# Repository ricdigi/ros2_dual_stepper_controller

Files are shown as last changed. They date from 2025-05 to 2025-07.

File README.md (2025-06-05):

## Introduction

This repository presents a complete example of how to repurpose an **ANET A8 3D printer motherboard** into a functional actuator system for a differential drive robot, fully integrated with the **ROS 2 control framework** (`ros2_control`). It provides both the **firmware** that runs on the microcontroller and the **hardware interface plugin** required to bridge the physical system with the ROS 2 ecosystem.

This project serves two main purposes:

1. **Hardware Repurposing Reference**: It provides a practical, working example of how inexpensive 3D printer electronics can be reused in robotics applications.
2. **ROS 2 Control Integration Example**: It offers a minimal but complete implementation of a custom hardware plugin for `ros2_control`, useful as a reference or learning resource.

The actuator system is composed of **two stepper motors**, each equipped with an **AS5600 absolute magnetic encoder** to track shaft position. The motors are driven by **A4988 stepper drivers** onboard the ANET A8 motherboard. The board uses an **Atmega1284p microcontroller**, which is compatible with the Arduino toolchain through the [Sanguino board definition](https://github.com/Lauszus/Sanguino), although it is not officially supported by the Arduino IDE.

All communication between the robot and the ROS 2 computer occurs over a **serial connection**, with velocity commands sent to the microcontroller and encoder data streamed back to the host. A **custom `SystemInterface` plugin** for `ros2_control` implements this logic, enabling real-time control and feedback integration.

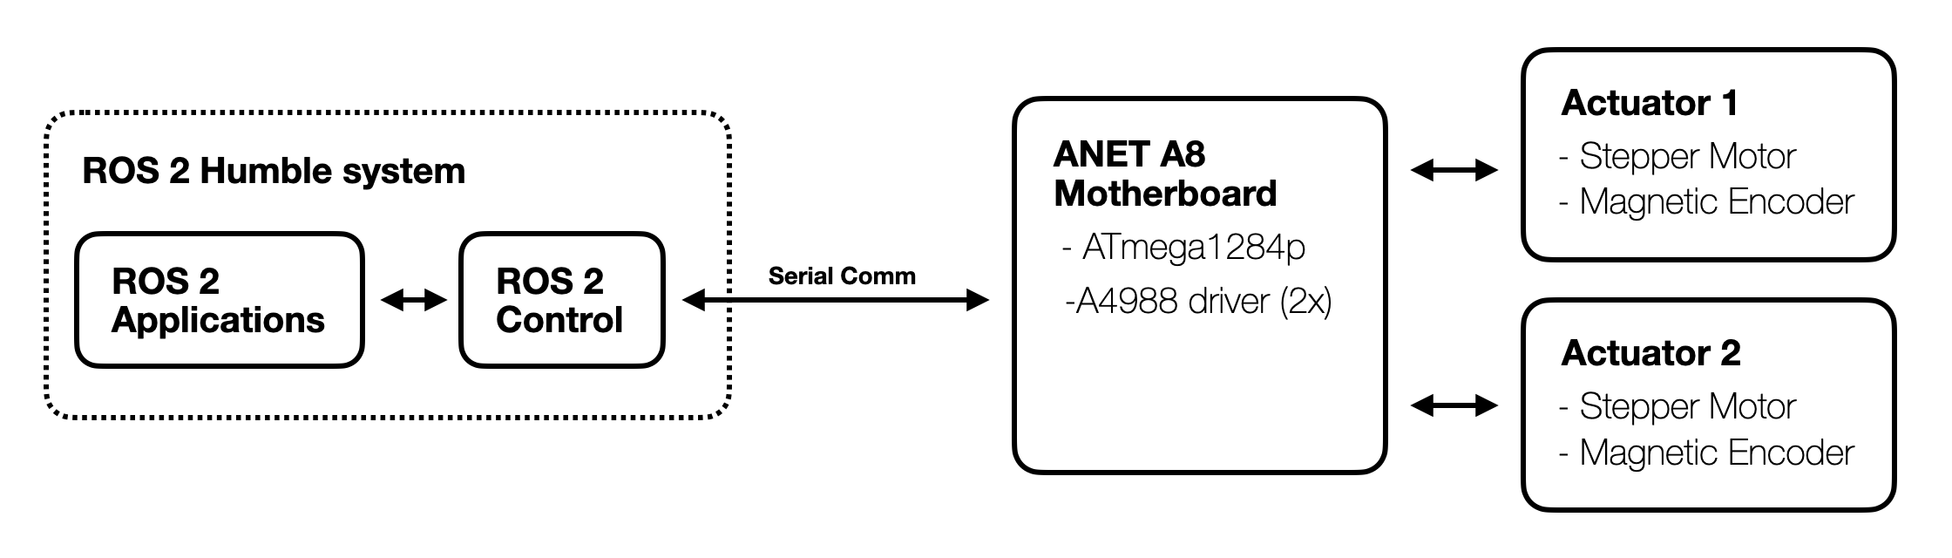
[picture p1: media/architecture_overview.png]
Dual Stepper Controller

**Figure 1:** System architecture overview. Two stepper actuators with magnetic encoders are driven by an ANET A8 3D printer board running custom firmware. The board communicates via serial with a ROS 2 Humble system, which uses ros2_control to manage real-time control and feedback integration.

<div style="display: flex; gap: 20px;">

  <div style="flex: 1;">
    <h3>Software Stack</h3>
    <table>
      <tr><th>Component</th><th>Description</th></tr>
      <tr><td><b>ROS 2 Humble</b></td><td>Target ROS 2 distribution</td></tr>
      <tr><td><code>ros2_control</code></td><td>Hardware abstraction & real-time control</td></tr>
      <tr><td><code>diff_drive_controller</code></td><td>Velocity command + odometry</td></tr>
      <tr><td><code>joint_state_broadcaster</code></td><td>Publishes joint states</td></tr>
      <tr><td><b>Launch & Config</b></td><td>YAML + launch files</td></tr>
    </table>
  </div>

  <div style="flex: 1;">
    <h3>Repository Contents</h3>
    <table>
      <tr><th>Path</th><th>Description</th></tr>
      <tr><td><code>src/, include/</code></td><td>C++ hardware plugin implementation</td></tr>
      <tr><td><code>description/urdf/</code></td><td>Xacro robot description</td></tr>
      <tr><td><code>config/</code></td><td>Controller YAML config</td></tr>
      <tr><td><code>launch/</code></td><td>System bringup launch files</td></tr>
      <tr><td><code>firmware/</code></td><td>Atmega1284p firmware source</td></tr>
    </table>
  </div>

</div>

The system is tested and functional. It supports closed-loop velocity control, publishes joint states, integrates cleanly with the ROS 2 navigation stack, and can be driven using tools such as `teleop_twist_keyboard` or custom commands. This setup is a solid foundation for building more complex mobile robots or for learning how to write real `ros2_control` hardware interfaces from scratch.

---

## Installing the Hardware Plugin

This section provides instructions for installing and using the custom hardware plugin developed for the `ros2_control` framework. It assumes a working installation of **ROS 2 Humble** and basic familiarity with ROS 2 concepts. Firmware installation for the ANET A8 board is addressed in a later section.

Begin by cloning this repository into the `src/` directory of your ROS 2 workspace:

```bash
cd ~/ros2_ws/src
git clone -b humble https://github.com/ricdigi/ros2_dual_stepper_controller.git
```

Next, ensure that all required system dependencies are installed. The plugin relies on core components of the ROS 2 control stack, including controller management and joint state broadcasting:

```bash
sudo apt install ros-humble-ros2-control \
                 ros-humble-ros2-controllers \
                 ros-humble-diff-drive-controller \
                 ros-humble-joint-state-broadcaster \
                 ros-humble-controller-manager \
                 ros-humble-robot-state-publisher \
                 ros-humble-xacro
```

Optional tools for manual control and visualization can be installed with:

```bash
sudo apt install ros-humble-teleop-twist-keyboard \
                 ros-humble-rviz2
```

After installing system packages, use `rosdep` to resolve any remaining ROS-specific dependencies:

```bash
cd ~/ros2_ws
rosdep install --from-paths src --ignore-src -r -y
```

Finally, build the workspace. Ensure your ROS 2 environment is properly sourced before compiling:

```bash
source /opt/ros/humble/setup.bash
colcon build --symlink-install
```

Once the build completes, source the workspace:

```bash
source install/setup.bash
```

You are now ready to launch and test the system.

## Launching the System
To bring up the dual stepper controller system, use the provided launch files. The main launch file is located in `launch/dual_stepper_controller.launch.py`. This file sets up the necessary nodes and configurations for the hardware interface, controllers, and robot state publisher. Moreover, it launches rviz2 for visualization and debugging.

Run the following command to start the system:

```bash
ros2 launch ros2_dual_stepper_controller test_hardware.launch.py
```

Note: the system will run only if the ANET A8 board is connected via USB and the firmware is correctly installed and running (see the Firmware section below).

## Installing the Firmware on the ANET A8 Board

The firmware is written in C++, and integrating some Arduino library syntax, for the **Atmega1284p** microcontroller on the ANET A8 motherboard. It implements a minimal serial protocol to receive velocity commands from the ROS 2 host and return encoder readings from the attached AS5600 sensors.

### Requirements

The firmware is designed to be compiled and uploaded using **PlatformIO**. To install PlatformIO, follow the instructions on the [official website](https://platformio.org/install/cli). A working Python installation is required. Moreover, make sure to install the shell commands.

### Uploading the Firmware

1. Navigate to the `firmware/` directory:

   ```bash
   cd firmware
   ```

2. Open the `platformio.ini` file and set the correct USB upload port:

   ```ini
   upload_port = /dev/ttyUSB0  ; or COM3 on Windows
   ```

3. Compile and upload the firmware:

   ```bash
   platformio run --target upload
   ```

After upload, the microcontroller will automatically reset and start listening for velocity commands over the specified serial port. Ensure that the serial port specified here matches the one configured in your ROS 2 `<ros2_control>` URDF tag.

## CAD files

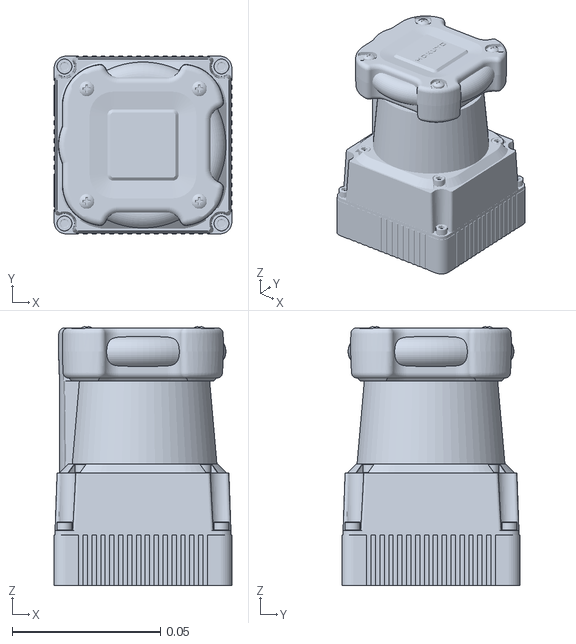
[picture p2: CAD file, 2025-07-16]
ros2_dual_stepper_controller/description/meshes/urdf_lidar_link.STL
0.06 x 0.06 x 0.0874

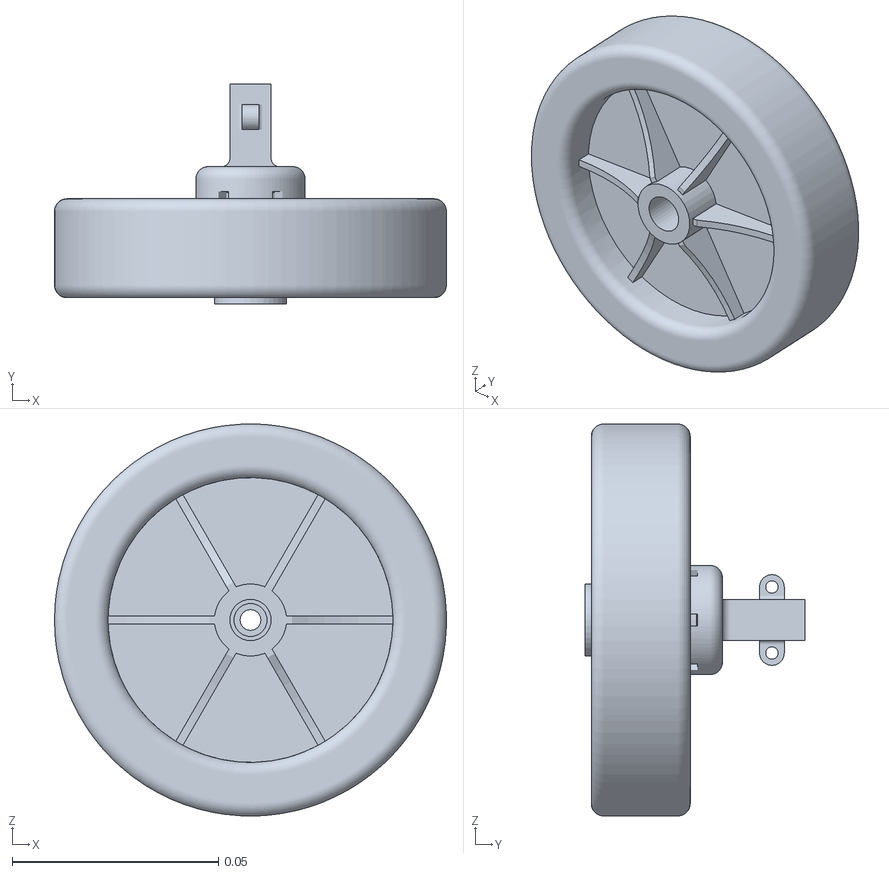
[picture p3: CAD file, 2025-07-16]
ros2_dual_stepper_controller/description/meshes/urdf_right_wheel.STL
0.095 x 0.0533 x 0.095

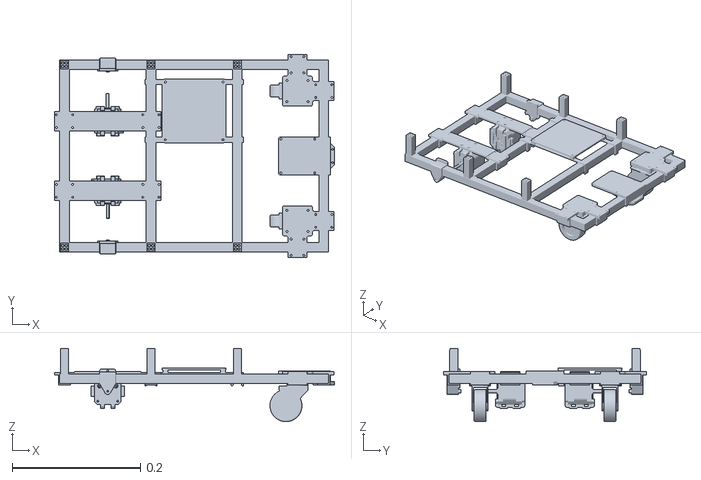
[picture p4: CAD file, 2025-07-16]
ros2_dual_stepper_controller/description/meshes/urdf_base_link.STL
0.437 x 0.316 x 0.115

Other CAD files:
ros2_dual_stepper_controller/description/meshes/urdf_left_wheel.STL

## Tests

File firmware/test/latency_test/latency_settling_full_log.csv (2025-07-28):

trial | command_speed | latency_A_s | settling_A_s | final_speed_A_rad_s | latency_B_s | settling_B_s | final_speed_B_rad_s
1 | 1 | 0.05195498466491699 | 0.7179610729217529 | 0.9109777196076042 | 0.05195498466491699 | 0.5636332035064697 | 1.0603183293793426
2 | 1 | 0.05062222480773926 | 0.665241003036499 | 0.9226189779441588 | 0.05062222480773926 | 0.5632681846618652 | 1.104117793277436
3 | 1 | 0.05112099647521973 | 1.1779839992523193 | 0.9384606225137686 | 0.05112099647521973 | 0.5633349418640137 | 1.0874226260873827
4 | 1 | 0.05090522766113281 | 1.0755772590637207 | 0.942892152980103 | 0.05090522766113281 | 0.5633761882781982 | 1.0626244898664654
5 | 1 | 0.05094504356384277 | 1.3314778804779053 | 0.9709866707975836 | 0.05094504356384277 | 0.7173449993133545 | 1.0606162096404375
6 | 1 | 0.051197052001953125 | 0.5634510517120361 | 0.9936742978209377 | 0.051197052001953125 | 0.5634510517120361 | 0.9640123784829994
7 | 1 | 0.0514678955078125 | 0.5636367797851562 | 1.0189075700281536 | 0.0514678955078125 | 0.5636367797851562 | 1.0039236351747984
8 | 1 | 0.050295114517211914 | 0.5627789497375488 | 1.0315156595297674 | 0.050295114517211914 | 0.5627789497375488 | 0.9119196410335626
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

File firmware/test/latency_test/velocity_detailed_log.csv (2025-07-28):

trial | command_speed | t_rel_s | speed_A_rad_s | speed_B_rad_s
1 | 1 | 5.245208740234375e-06 | 0.0 | 0.0
1 | 1 | 0.05195498466491699 | 0.0 | 0.0
1 | 1 | 0.10263609886169434 | 0.9266882761251614 | 1.0313143718167117
1 | 1 | 0.15500998497009277 | 0.878219069596251 | 1.0121846903821197
1 | 1 | 0.2053210735321045 | 0.896322442193293 | 1.030770808522287
1 | 1 | 0.25636982917785645 | 0.9383085539670258 | 1.029112607576738
1 | 1 | 0.30817723274230957 | 0.9395722179290454 | 0.9544860626580779
1 | 1 | 0.3590881824493408 | 0.9258988858353547 | 0.970700444827388
1 | 1 | 0.41109704971313477 | 0.9091818350935206 | 0.9986095565781292
1 | 1 | 0.4609348773956299 | 0.9338232222367773 | 0.9940698817359241
1 | 1 | 0.512871265411377 | 0.9495606423864049 | 0.979705424684386
1 | 1 | 0.5636332035064697 | 0.9410162102592919 | 0.9410162102592919
1 | 1 | 0.6151840686798096 | 0.9445620347557494 | 0.9295689865850232
1 | 1 | 0.6661620140075684 | 0.9575334966324326 | 0.9575334966324326
1 | 1 | 0.7179610729217529 | 0.955221171786362 | 0.9701465025955239
1 | 1 | 0.7682130336761475 | 0.9920795728376671 | 0.9469850467995913
1 | 1 | 0.8190550804138184 | 1.0166449558981485 | 0.9256021240266726
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

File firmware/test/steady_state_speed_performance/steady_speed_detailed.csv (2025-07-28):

speed_cmd | t_rel_s | speed_A_rad_s | speed_B_rad_s
1 | 2.86102294921875e-06 | 0.0 | 0.0
1 | 0.050805091857910156 | 0.0 | 0.0
1 | 0.1025087833404541 | 0.937713787923541 | 0.9954825095430997
1 | 0.1540818214416504 | 0.9437746962943625 | 1.0026207176531623
1 | 0.20502209663391113 | 0.9293156142421574 | 1.019986010354711
1 | 0.25634312629699707 | 0.913341494696821 | 0.9880537948760059
1 | 0.30750083923339844 | 0.9084978472962294 | 0.9530986447750461
1 | 0.35935020446777344 | 0.8990193415768836 | 0.9591214867322456
1 | 0.4098389148712158 | 0.9281069614552987 | 0.9582041818496039
1 | 0.4618031978607178 | 0.9147720534209377 | 0.9597317627964008
1 | 0.5121328830718994 | 0.9009118018593174 | 0.9609524051913303
1 | 0.5639588832855225 | 0.8916313020503461 | 0.9213012753006304
1 | 0.615380048751831 | 0.9189207426508554 | 0.903644892283074
1 | 0.6658151149749756 | 0.9100567335579431 | 0.9249649724699956
1 | 0.7182040214538574 | 0.9091544558077919 | 0.9540128266531087
1 | 0.7687270641326904 | 0.9171020075468471 | 0.9321103296380221
1 | 0.8202388286590576 | 0.8985275996441486 | 0.8985966202976564
1 | 0.8711471557617188 | 0.9137880634216584 | 0.8983874994138119
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

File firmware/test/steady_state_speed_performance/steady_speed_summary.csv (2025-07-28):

speed_cmd | mean_A | var_A | mean_B | var_B
1 | 0.9379930550611228 | 0.02512550847551385 | 0.9512288440492325 | 0.028967239236724823
2 | 1.8813192590659922 | 0.10241610395930446 | 1.855105754485178 | 0.11370370867157845
3 | 2.710207250890758 | 0.21086324102078086 | 2.7307851925532067 | 0.24322223736391882
4 | 3.7496076464588 | 0.407146145631891 | 3.7560157987148037 | 0.45565493381201394
5 | 4.34962850640288 | 0.5407979296141942 | 4.335710527276916 | 0.6206530288169179
6 | 5.0768347740161435 | 0.7369922002447348 | 5.066014080429801 | 0.8230169061039279
7 | 6.115582127762878 | 1.0699874008021533 | 6.106970015088197 | 1.1949336709981797
8 | 6.20608095300346 | 1.0957266097221696 | 6.1998687360887015 | 1.2365705162528418
9 | 7.788772619028401 | 1.7168338612194005 | 7.786601863923971 | 1.928112245700377
10 | 7.7789119484647475 | 1.7156860966667897 | 7.7745415028241105 | 1.9281858458321963
11 | 7.947296141664224 | 1.7897347631810498 | 7.944181709162227 | 2.0086555463194857
12 | 10.603765623973766 | 3.126824671592498 | 10.583506801079437 | 3.447509448451753
13 | 10.60080912651259 | 3.1339551891880992 | 10.580594900284808 | 3.460565832098273
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

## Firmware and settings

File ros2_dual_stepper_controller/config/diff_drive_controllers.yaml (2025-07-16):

controller_manager:
  ros__parameters:
    update_rate: 100

    joint_state_broadcaster:
      type: joint_state_broadcaster/JointStateBroadcaster

    diff_drive_controller:
      type: diff_drive_controller/DiffDriveController

diff_drive_controller:
  ros__parameters:
    left_wheel_names: ["left_wheel_joint"]
    right_wheel_names: ["right_wheel_joint"]

    wheel_separation: 0.235
    wheel_radius: 0.0475

    base_frame_id: base_link

    use_stamped_vel: false
    cmd_vel_timeout: 0.5

    publish_rate: 50.0

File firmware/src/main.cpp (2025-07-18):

#include <Arduino.h>
#include <Wire.h>

#include "StepperMotor.h"
#include "SerialComm.h"
#include "MagneticEncoder.h"

#define STEP_PIN_A       15
#define STEP_DIR_PIN_A   21

#define STEP_PIN_B       22
#define STEP_DIR_PIN_B   23

#define ENABLE_PIN_AB    14

#define MUX_PIN_A        27
#define MUX_PIN_B        28

#define DIR_PIN_A        29
#define DIR_PIN_B        30

StepperMotor stepper_A(STEP_PIN_A, STEP_DIR_PIN_A, ENABLE_PIN_AB, 200, 16);
StepperMotor stepper_B(STEP_PIN_B, STEP_DIR_PIN_B, ENABLE_PIN_AB, 200, 16);

MagneticEncoder encoders;
SerialComm comm;

void setup() {
  comm.begin(115200);
  Wire.begin();

  stepper_A.setRotationDir(false);
  stepper_B.setRotationDir(true);

  stepper_A.setUpEnablePin();
  stepper_B.setUpEnablePin();

  stepper_A.setSpeedRad(0);
  stepper_B.setSpeedRad(0);

  stepper_A.setAccelerationRad(100);
  stepper_B.setAccelerationRad(100);

  encoders.encoderInit(MUX_PIN_A, MUX_PIN_B, DIR_PIN_A, DIR_PIN_B);

}

void loop() {

  comm.receive();

  if (comm.hasCommand()) {
    uint8_t command = comm.getCommand();
    if (command == SerialComm::ENABLE_CMD) {
      stepper_A.enable();
      stepper_B.enable();
    } else if (command == SerialComm::DISABLE_CMD) {
      stepper_A.disable();
      stepper_B.disable();
    } else if (command == SerialComm::VEL_CMD) {
      float speed_A = comm.getSpeedA();
      float speed_B = comm.getSpeedB();

      stepper_A.setSpeedRad(speed_A);
      stepper_B.setSpeedRad(speed_B);
    }
    comm.clearCommand();
  }

  if (encoders.readSensors()) {
    comm.sendEncoderData(encoders.getEncoderAData(), encoders.getEncoderBData());
  }

  stepper_A.run();
  stepper_B.run();

}

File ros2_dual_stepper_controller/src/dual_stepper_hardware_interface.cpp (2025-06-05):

#include "ros2_dual_stepper_controller/dual_stepper_hardware_interface.hpp"
#include "ros2_dual_stepper_controller/serial_comm.hpp"
#include "ros2_dual_stepper_controller/wheel_joint.hpp"

#include <chrono>
#include <cmath>
#include <cstddef>
#include <iomanip>
#include <limits>
#include <memory>
#include <sstream>
#include <vector>
#include <cstring>
#include <termios.h>

#include "hardware_interface/lexical_casts.hpp"
#include "hardware_interface/types/hardware_interface_type_values.hpp"
#include "rclcpp/rclcpp.hpp"

#define M_PI 3.14159265358979323846

namespace dual_stepper_hardware_interface
{

hardware_interface::CallbackReturn DualStepperHardwareInterface::on_init(const hardware_interface::HardwareInfo & info) {

    // Call the parent class default on_init() method
    if (hardware_interface::SystemInterface::on_init(info) != hardware_interface::CallbackReturn::SUCCESS) {
        return hardware_interface::CallbackReturn::ERROR;
    }

    /* The default on_init() method processes the HardwareInfo object, which contains hardware details parsed from the
     * robot's URDF. This parsing is performed by the Resource Manager using the function
     * parse_control_resources_from_urdf(), defined in
     * ros2_control/hardware_interface/include/hardware_interface/component_parser.hpp.
     */

    logger_ = std::make_shared<rclcpp::Logger>(rclcpp::get_logger("dual_stepper_hardware_interface"));
    clock_ = std::make_shared<rclcpp::Clock>(rclcpp::Clock());

    if (info_.joints.size() != 2) {
        RCLCPP_FATAL(get_logger(), "Expected exactly 2 joints, got %zu", info_.joints.size());
        return hardware_interface::CallbackReturn::ERROR;
    }

    // Initialize the wheel joints with the parameters from the hardware info
    left_wheel_.name = info_.joints[0].name;
    right_wheel_.name = info_.joints[1].name;

    RCLCPP_INFO(get_logger(), "Left joint name: '%s'", left_wheel_.name.c_str());
    RCLCPP_INFO(get_logger(), "Right joint name: '%s'", right_wheel_.name.c_str());

    RCLCPP_INFO(get_logger(), "Successfully initialized!");
    return hardware_interface::CallbackReturn::SUCCESS;

}


hardware_interface::CallbackReturn DualStepperHardwareInterface::on_configure(const rclcpp_lifecycle::State & /*previous_state*/) {

    // Configure and initialize the serial port and baud rate from the hardware parameters
    serial_comm_ = SerialComm();
    serial_comm_.setSerialPort(info_.hardware_parameters.at("serial_port"));
    serial_comm_.setBaudRate(std::stoi(info_.hardware_parameters.at("baud_rate")));
    if (serial_comm_.init() != hardware_interface::CallbackReturn::SUCCESS) {
        return hardware_interface::CallbackReturn::ERROR;
    }

    RCLCPP_INFO(get_logger(), "Successfully configured!");
    return hardware_interface::CallbackReturn::SUCCESS;

}


std::vector<hardware_interface::StateInterface> DualStepperHardwareInterface::export_state_interfaces() {
  // We need to set up a position and a velocity interface for each wheel
  std::vector<hardware_interface::StateInterface> state_interfaces;

  state_interfaces.emplace_back(hardware_interface::StateInterface(left_wheel_.name, hardware_interface::HW_IF_POSITION, &left_wheel_.total_position_rad));
  state_interfaces.emplace_back(hardware_interface::StateInterface(left_wheel_.name, hardware_interface::HW_IF_VELOCITY, &left_wheel_.velocity_rad_s));

  state_interfaces.emplace_back(hardware_interface::StateInterface(right_wheel_.name, hardware_interface::HW_IF_POSITION, &right_wheel_.total_position_rad));
  state_interfaces.emplace_back(hardware_interface::StateInterface(right_wheel_.name, hardware_interface::HW_IF_VELOCITY, &right_wheel_.velocity_rad_s));

  return state_interfaces;
}


std::vector<hardware_interface::CommandInterface> DualStepperHardwareInterface::export_command_interfaces() {
  // We need to set up a velocity command interface for each wheel
  std::vector<hardware_interface::CommandInterface> command_interfaces;

  command_interfaces.emplace_back(hardware_interface::CommandInterface(left_wheel_.name, hardware_interface::HW_IF_VELOCITY, &left_wheel_.commanded_velocity_rad_s));
  command_interfaces.emplace_back(hardware_interface::CommandInterface(right_wheel_.name, hardware_interface::HW_IF_VELOCITY, &right_wheel_.commanded_velocity_rad_s));

  return command_interfaces;
}


hardware_interface::return_type DualStepperHardwareInterface::read(
    const rclcpp::Time & time, const rclcpp::Duration & period) {

    readEncoderData(period);

    return hardware_interface::return_type::OK;
}


hardware_interface::return_type DualStepperHardwareInterface::write(
    const rclcpp::Time & time, const rclcpp::Duration & period) {

    if (!sendVelocityCommand()) {
        RCLCPP_ERROR(get_logger(), "Failed to send velocity command to the stepper motors.");
        return hardware_interface::return_type::ERROR;
    }

    return hardware_interface::return_type::OK;
}


void DualStepperHardwareInterface::readEncoderData(const rclcpp::Duration & period) {
    const auto timeout_start = clock_->now();
    const rclcpp::Duration timeout(0, 5e6);  // 5 milliseconds

    uint8_t cmd;
    float tmp;
    std::vector<uint8_t> data;

    while ((clock_->now() - timeout_start) < timeout) {
        if (serial_comm_.receive(cmd, data)) {
            if (cmd == SerialComm::ENC_CMD && data.size() == SerialComm::ENC_DATA_LEN) {
                std::memcpy(&tmp, &data[0], 4);
                left_wheel_.position_rad = static_cast<double>(tmp) * (M_PI / 180.0);

                std::memcpy(&tmp, &data[4], 4);
                right_wheel_.position_rad = static_cast<double>(tmp) * (M_PI / 180.0);

                left_wheel_.updateTotalPositionRad();
                right_wheel_.updateTotalPositionRad();

                left_wheel_.computeVelocityRadS(period.seconds(), get_logger());
                right_wheel_.computeVelocityRadS(period.seconds(), get_logger());
		
		        //RCLCPP_INFO(get_logger(), "Updated encoder positions: L=%.3f R=%.3f", left_wheel_.position_rad, right_wheel_.position_rad);
		        tcflush(serial_comm_.getFD(), TCIFLUSH);

                return;  // Successfully read one full packet, done
		
            }
        }
    }

    RCLCPP_WARN_THROTTLE(get_logger(), *clock_, 2000, "No encoder packet received in last cycle.");
}


bool DualStepperHardwareInterface::sendVelocityCommand() {
    std::vector<uint8_t> data(SerialComm::VEL_DATA_LEN);
    uint8_t cmd = SerialComm::VEL_CMD;

    float left_speed = static_cast<float>(left_wheel_.commanded_velocity_rad_s);
    float right_speed = static_cast<float>(right_wheel_.commanded_velocity_rad_s);

    memcpy(&data[0], &left_speed, sizeof(float));
    memcpy(&data[4], &right_speed, sizeof(float));

    // Send the command via serial communication
    return serial_comm_.send(cmd, data);
}


} // namespace dual_stepper_hardware_interface
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

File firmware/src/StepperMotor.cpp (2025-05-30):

#include "../include/StepperMotor.h"
#include <Arduino.h>
#include <math.h>

StepperMotor::StepperMotor(uint8_t stepPin_, uint8_t dirPin_, uint8_t enablePin_, int stepsPerRev_, int microstepping_)
  : stepPin(stepPin_), dirPin(dirPin_), enablePin(enablePin_), stepsPerRev(stepsPerRev_), microstepping(microstepping_) {

    stepper = AccelStepper(AccelStepper::DRIVER, stepPin, dirPin);
    computeConversionFactor();

  }

void StepperMotor::computeConversionFactor(){
  radToMicrosteps = float(stepsPerRev * microstepping) / (2.0f * PI);
}

void StepperMotor::setUpEnablePin(){
  pinMode(enablePin, OUTPUT);
  digitalWrite(enablePin, LOW); 
}

float StepperMotor::toMicrostep(float radValue){
  return radValue * radToMicrosteps;
}

void StepperMotor::setAccelerationRad(float radPerSec2){
  accelerationRad = radPerSec2;
  stepper.setAcceleration(this->toMicrostep(accelerationRad));
}

void StepperMotor::setSpeedRad(float radPerSec){
  targetSpeedRad = radPerSec;
  maxSpeedMicrosteps = toMicrostep(targetSpeedRad);
  stepper.setMaxSpeed(fabs(maxSpeedMicrosteps));
  stepper.setSpeed(maxSpeedMicrosteps);
}

void StepperMotor::enable(){
  digitalWrite(enablePin, LOW); 
}

void StepperMotor::disable(){
  digitalWrite(enablePin, HIGH); 
}

void StepperMotor::run(){
  stepper.runSpeed();
}

void StepperMotor::stop(){
  stepper.stop();  // decelerate
  while (stepper.isRunning()) stepper.run();
}

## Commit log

2025-05-27 major developments in the hardware interface - not working yet
    [dual_stepper_hardware_interface.cpp, main.cpp]
2025-05-28 added robot description urdf and meshes
    [base_link.xacro, dual_stepper.ros2_control.xacro, dual_stepper.urdf.xacro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]
2025-05-28 modified CmakeList to include urdf
2025-05-28 corrected header file path in .cpp files
    [dual_stepper_hardware_interface.cpp]
2025-05-28 second correction of header imports
    [dual_stepper_hardware_interface.cpp]
2025-05-28 corrected first batch of building errors
    [dual_stepper_hardware_interface.cpp]
2025-05-28 updated xacro
    [base_link.xacro, wheel.xacro]
2025-05-28 corrected xacro
    [base_link.xacro, dual_stepper.ros2_control.xacro, dual_stepper.urdf.xacro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]
2025-05-28 corrected joint rotation axis
    [dual_stepper.urdf.xacro]
2025-05-28 added launch and config
    [base_link.xacro, diff_drive_controllers.yaml, dual_stepper.ros2_control.xacro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]
2025-05-29 corrected plugin name and add test
    [MagneticEncoder.cpp]
2025-05-29 corrected cstring import in test
    [dual_stepper_hardware_interface.cpp]
2025-05-29 corrected package xml
    [dual_stepper.ros2_control.xacro]
2025-05-29 moved wheels initialization in on_init()
2025-05-29 added velocity debug print
2025-05-30 optimized firmware efficiency and added motor speed test
2025-05-30 added new wheels STL
    [urdf_left_wheel.STL, urdf_right_wheel.STL, urdf_wheel.STL]
2025-05-30 updated xacro file for new meshes
    [dual_stepper.urdf.xacro, wheel.xacro]
2025-05-30 updated velocity computation
    [dual_stepper.urdf.xacro]
2025-05-30 added deg2rad conversion
    [dual_stepper.urdf.xacro]
2025-07-16 new meshes for new design
    [diff_drive_controllers.yaml, dual_stepper.urdf.xacro, lidar.xacro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]
2025-07-16 modified mesh parameters
    [base_link.xacro, lidar.xacro]
2025-07-16 removed z offset in base_link
    [base_link.xacro]
2025-07-16 simplified launch file
    [diff_drive_controllers.yaml]
2025-07-16 added lidar to launch
2025-07-16 corrected lidar launch
2025-07-18 updated magnetic rotation direction
2025-07-18 updated launch file - removed lidar
2025-07-28 new tests and results
    [latency_settling_full_log.csv, max_speed_test.csv, steady_speed_detailed.csv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]
